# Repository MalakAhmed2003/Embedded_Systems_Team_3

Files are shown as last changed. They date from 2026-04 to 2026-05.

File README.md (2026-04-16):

# Embedded Systems Course Project

The following repository contains different files of code for running a Maze Solver Robot that explores any given maze then generates the optimized path to run 
between the start and end points, then runs on this optimized path.
The Robot also has a bluetooth module that connects to the laptop and can be controlled through a custom website (which you can also filnd its python code here).
## Exploration and Optimized Path:
To get the Robot to explore and optimize the path taken to solve the maze:
1- Upload the Maze_Solver.ino code to the Robot Arduino 
2- Power up the system with ~ 9.4-9.6 V

### Hardware Architecture


### Code Architecture
maze_robot_architecture

## Running the Website:
To run the Website correctly and connect it to the Arduino through the HC-10 Bluetooth Module, follow the following steps:

1- Pair with HMSOFT.

2- Make sure it appears in the Bluetooth tab in the device manager.

3- In the Bluetooth tab in the Device Manager--> HMSOFT--> Details tab --> Bluetooth Device Address in the drop list --> (34:03:de:34:c7:9e)

4- Run hc10_bridge.py after changing the HC-10 known addresses to the address found in the device manager.

5- Run the Website.py

6- Change the serial print and read in Arduino code to be serial#, where # is based on the pins you are connecting your Hc-10 module to.

The Website should look like:


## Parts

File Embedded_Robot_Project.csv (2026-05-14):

Reference | Qty | Value | Datasheet | MP | Description
C1,C2 | 2 | 220u | https://www.lcsc.com/datasheet/C2163363.pdf |  | Polarized capacitor, small US symbol
C3,C8 | 2 | 15p | https://eu.mouser.com/datasheet/3/76/1/GRM022R60G474ME15-01A.pdf | GRM022R60G474ME15L | SMD capacitor X5R(EIA) with capacitance 0.47uF Tol.20%. Rated voltage 4Vdc 85C
C4 | 1 | 1u | https://eu.mouser.com/datasheet/3/76/1/GRM022R60G474ME15-01A.pdf | GRM022R60G474ME15L | SMD capacitor X5R(EIA) with capacitance 0.47uF Tol.20%. Rated voltage 4Vdc 85C
C5,C6 | 2 | 12p | https://eu.mouser.com/datasheet/3/76/1/GRM022R60G474ME15-01A.pdf | GRM022R60G474ME15L | SMD capacitor X5R(EIA) with capacitance 0.47uF Tol.20%. Rated voltage 4Vdc 85C
C7,C26,C27,C28,C29,C32,C34 | 7 | 100n | https://eu.mouser.com/datasheet/3/76/1/GRM022R60G474ME15-01A.pdf | GRM022R60G474ME15L | SMD capacitor X5R(EIA) with capacitance 0.47uF Tol.20%. Rated voltage 4Vdc 85C
C9,C10 | 2 | 18p | https://eu.mouser.com/datasheet/3/76/1/GRM022R60G474ME15-01A.pdf | GRM022R60G474ME15L | SMD capacitor X5R(EIA) with capacitance 0.47uF Tol.20%. Rated voltage 4Vdc 85C
C11,C12,C13 | 3 | 1p | https://eu.mouser.com/datasheet/3/76/1/GRM022R60G474ME15-01A.pdf | GRM022R60G474ME15L | SMD capacitor X5R(EIA) with capacitance 0.47uF Tol.20%. Rated voltage 4Vdc 85C
C14,C15 | 2 | 47u | https://eu.mouser.com/datasheet/3/76/1/GRM022R60G474ME15-01A.pdf |  | Polarized capacitor
C16,C17,C18,C19,C20,C21,C22,C23,C24,C25 | 10 | 0u1 | https://eu.mouser.com/datasheet/3/76/1/GRM022R60G474ME15-01A.pdf | GRM022R60G474ME15L | SMD capacitor X5R(EIA) with capacitance 0.47uF Tol.20%. Rated voltage 4Vdc 85C
C30,C31 | 2 | 22p | https://eu.mouser.com/datasheet/3/76/1/GRM022R60G474ME15-01A.pdf | GRM022R60G474ME15L | SMD capacitor X5R(EIA) with capacitance 0.47uF Tol.20%. Rated voltage 4Vdc 85C
C33 | 1 | 10u | https://eu.mouser.com/datasheet/3/76/1/GRM022R60G474ME15-01A.pdf | GRM022R60G474ME15L | SMD capacitor X5R(EIA) with capacitance 0.47uF Tol.20%. Rated voltage 4Vdc 85C
D1,D2,D3,D4,D5,D6,D7,D8,D9,D10,D19,D21,D22 | 13 | LED | https://www.digikey.com/en/products/detail/kingbright/APT2012SURCK/1747532 | APT2012SURCK | Light emitting diode
D11,D12,D13,D14,D15,D16,D17,D18 | 8 | 1N4007 | http://www.vishay.com/docs/88503/1n4001.pdf |  | 1000V 1A General Purpose Rectifier Diode, DO-41
D20 | 1 | 1N4001 | http://www.vishay.com/docs/88503/1n4001.pdf |  | 50V 1A General Purpose Rectifier Diode, DO-41
F1 | 1 | MF-MSMF050-2 | https://www.lcsc.com/datasheet/C17313.pdf | MF-MSMF050-2 | Fuse, Resettable, 100A, Sz 4532, 0.186x0.134x0.033, SMT, 15VDC, DCR 0.15 Ohms | Bourns MF-MSMF050-2
FL1 | 1 | BLM21SP111SH1D | https://pim.murata.com/asset/pim4/ferriteBeadInductortypefilter/QNFA9102_PDF_FERRITEBEADINDUCTORTYPEFILTER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 | BLM21SP111SH1D | Ferrite Beads Multi-Layer Power 110Ohm 25% 100MHz 5A 0.013Ohm DCR 0805 Automotive T/R
J1,J2,J4 | 3 | Screw_Terminal_01x02 | https://www.lcsc.com/datasheet/C590402.pdf |  | Generic screw terminal, single row, 01x02, script generated (kicad-library-utils/schlib/autogen/connector/)
J3 | 1 | Screw_Terminal_01x03 | https://www.lcsc.com/datasheet/C5172715.pdf |  | Generic screw terminal, single row, 01x03, script generated (kicad-library-utils/schlib/autogen/connector/)
J6 | 1 | USB_B | https://www.lcsc.com/datasheet/C720549.pdf | 292304-1 | Type B Standard USB Connector 4 Position Right Angle Mount 1 Port | TE Connectivity 292304-1
L1,L2 | 2 | 2n | https://www.lcsc.com/datasheet/C76769.pdf | MLG1005S2N0BT000 | 2 nH Unshielded Multilayer Inductor 900 mA 150mOhm Max 0402 (1005 Metric)
L3 | 1 | 1n | https://www.lcsc.com/datasheet/C76769.pdf | MLG1005S2N0BT000 | 2 nH Unshielded Multilayer Inductor 900 mA 150mOhm Max 0402 (1005 Metric)
L4 | 1 | 3n | https://www.lcsc.com/datasheet/C76769.pdf | MLG1005S2N0BT000 | 2 nH Unshielded Multilayer Inductor 900 mA 150mOhm Max 0402 (1005 Metric)
R1,R3,R5,R6,R8,R9,R12,R13,R14,R17,R18,R19,R22,R23,R24,R26,R28,R32,R33,R34,R35,R36,R37 | 23 | 1K | https://www.mouser.com/catalog/specsheets/YAGEO_PYu_RC_Group_51_RoHS_L_12.pdf | RC0100FR-071KL | 1 kOhms ±1% 0.03W, 1/32W Chip Resistor 01005 (0402 Metric) Moisture Resistant Thick Film
R2,R4,R7,R10,R11,R15,R16,R20,R21,R25 | 10 | 10K | https://www.mouser.com/catalog/specsheets/YAGEO_PYu_RC_Group_51_RoHS_L_12.pdf | RC0100FR-071KL | 1 kOhms ±1% 0.03W, 1/32W Chip Resistor 01005 (0402 Metric) Moisture Resistant Thick Film
R27 | 1 | 56K | https://www.mouser.com/catalog/specsheets/YAGEO_PYu_RC_Group_51_RoHS_L_12.pdf | RC0100FR-071KL | 1 kOhms ±1% 0.03W, 1/32W Chip Resistor 01005 (0402 Metric) Moisture Resistant Thick Film
R29 | 1 | 2K | https://www.mouser.com/catalog/specsheets/YAGEO_PYu_RC_Group_51_RoHS_L_12.pdf | RC0100FR-071KL | 1 kOhms ±1% 0.03W, 1/32W Chip Resistor 01005 (0402 Metric) Moisture Resistant Thick Film
R30,R31 | 2 | 1M | https://www.mouser.com/catalog/specsheets/YAGEO_PYu_RC_Group_51_RoHS_L_12.pdf | RC0100FR-071KL | 1 kOhms ±1% 0.03W, 1/32W Chip Resistor 01005 (0402 Metric) Moisture Resistant Thick Film
RV1,RV2 | 2 | CG0603MLC-05E | https://eu.mouser.com/datasheet/3/40/1/cg0603mlc_05e_cg0603mlc_12e.pdf | CG0603MLC-05E | Varistor, ESD Clamp Protector, 5 VDC, 20 Vclamp, IEC 61000-4-2 Level 4, 0603 SMD | Bourns CG0603MLC-05E
S1 | 1 | TS20-42-25-WT-160-SMT-TR | https://www.lcsc.com/datasheet/C6886437.pdf | TS20-42-25-WT-160-SMT-TR | 4.2 x 3.2 mm, 2.5 mm Actuator Height, 160 gf, White, Surface Mount, TR, SPST, Tactile Switch
U1,U3,U5,U7,U9 | 5 | TCRT5000 | https://www.lcsc.com/datasheet/C24085.pdf | TCRT5000 | 950 nm 60 mA Through Hole Reflective Optical Sensor with Transistor Output
U2,U4,U6,U8,U10 | 5 | LM393AD | https://www.ti.com/lit/ds/symlink/lm193.pdf?HQS=dis-mous-null-mousermode-dsf-pf-null-wwe&ts=1778583813238 | LM393AD | Precision dual differential comparator, industrial grade
U11 | 1 | L298N | http://www.st.com/st-web-ui/static/active/en/resource/technical/document/datasheet/CD00000240.pdf |  | Dual full bridge motor driver, up to 46V, 4A, Multiwatt15-V
U12 | 1 | KA78M05_TO252 | https://www.onsemi.com/pub/Collateral/MC78M00-D.PDF |  | Positive 500mA 35V Linear Regulator, Fixed Output 5V, TO-252 (D-PAK)
U13 | 1 | CC2540F256RHAT | https://www.ti.com/lit/ds/symlink/cc2540.pdf?ts=1778516829410 | CC2540F256RHAT | Bluetooth® Low Energy wireless MCU with USB
U14 | 1 |  | https://www.ti.com/lit/an/swra117d/swra117d.pdf |  | 2.4 GHZ Antenna
U15 | 1 | ATmega2560-16A | http://ww1.microchip.com/downloads/en/DeviceDoc/Atmel-2549-8-bit-AVR-Microcontroller-ATmega640-1280-1281-2560-2561_datasheet.pdf |  | 16MHz, 256kB Flash, 8kB SRAM, 4kB EEPROM, JTAG, TQFP-100
U16 | 1 | ATmega16U2-M | http://ww1.microchip.com/downloads/en/DeviceDoc/doc7799.pdf |  | 16MHz, 16kB Flash, 512B SRAM, 512B EEPROM, QFN-32
U17 | 1 | NCP1117-3.3_TO252 | http://www.onsemi.com/pub_link/Collateral/NCP1117-D.PDF |  | 1A Low drop-out regulator, Fixed Output 3.3V, TO-252 (DPAK)
VR3,VR4,VR5,VR6,VR7 | 5 | Variable_Resistor_3362P | https://www.lcsc.com/datasheet/C48997906.pdf | 3362P-1-103RLF | TRIMMER - 1/4in SQ ST CERMET | Bourns 3362P-1-103RLF
Y1 | 1 | 32K | https://www.lcsc.com/datasheet/C6524090.pdf | SXT2248BB48-32.000M | Crystal 32MHz ±30ppm (Tol) ±30ppm (Stability) 8pF FUND 60Ohm Medical 4-Pin Ultra Mini-CSMD T/R
Y2 | 1 | 32M | https://www.lcsc.com/datasheet/C6524090.pdf | SXT2248BB48-32.000M | Crystal 32MHz ±30ppm (Tol) ±30ppm (Stability) 8pF FUND 60Ohm Medical 4-Pin Ultra Mini-CSMD T/R
Y3 | 1 | 16M | https://www.lcsc.com/datasheet/C6524090.pdf | SXT2248BB48-32.000M | Crystal 32MHz ±30ppm (Tol) ±30ppm (Stability) 8pF FUND 60Ohm Medical 4-Pin Ultra Mini-CSMD T/R
Y4 | 1 | 16M | https://www.lcsc.com/datasheet/C341521.pdf | CSTCE16M0V53R0 | RESONATOR, CERAMIC, 16MHZ, SMD; Frequency:16MHz; Oscillator Mounting:SMD; No. of Pins:3 Pin; Resonant Impedance:40ohm; Frequency Tolerance:± 0.5%; Product Range:-; Frequency Stability:-; Operating Temperature Min:-20°C; Operating Temperature Max:80°C; SVHC:No SVHC (07-Jul-2017); No. of Pins:3Pins

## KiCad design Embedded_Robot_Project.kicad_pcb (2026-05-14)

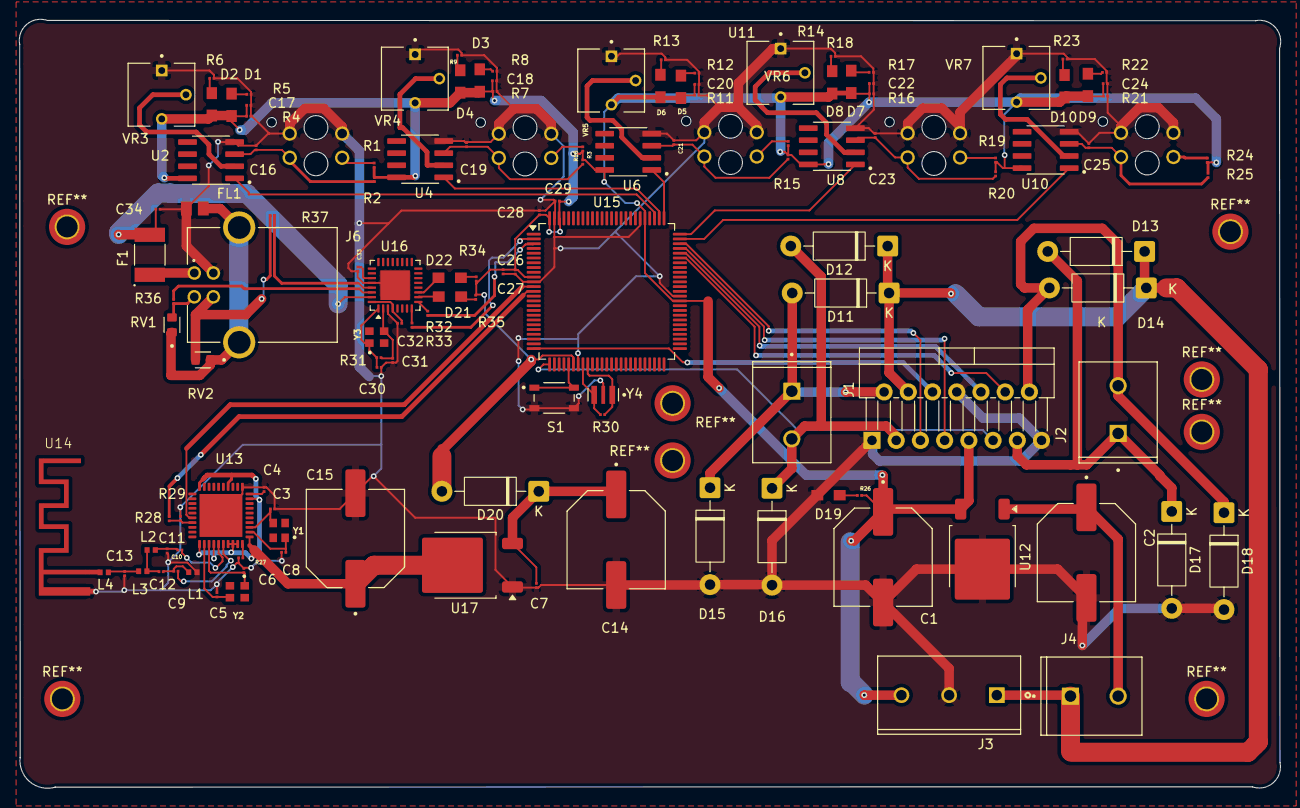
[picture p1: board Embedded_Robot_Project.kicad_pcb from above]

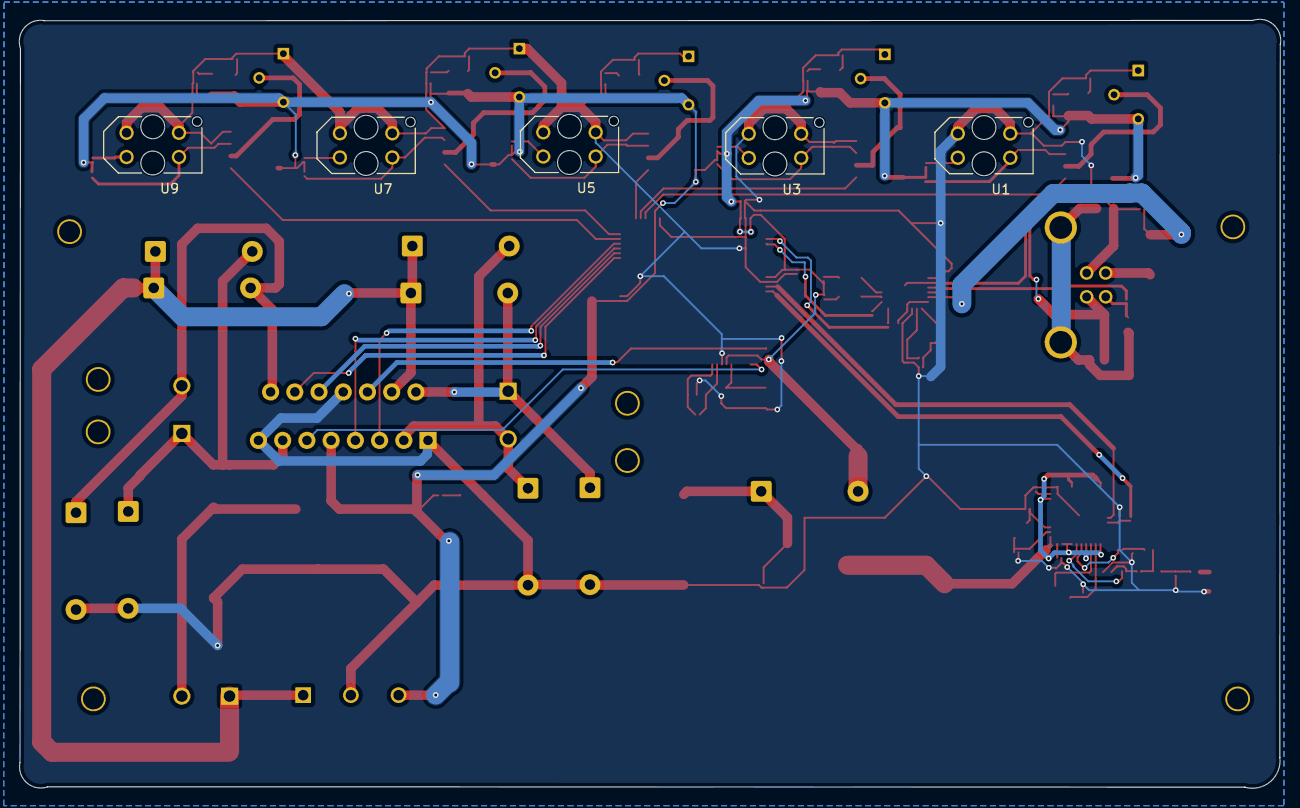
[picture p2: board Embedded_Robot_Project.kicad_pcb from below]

Board: 2 copper layers, 132.3 x 80.6 mm, 133 parts (5 on the bottom side), 85 nets.

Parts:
C1, C2: C_Polarized_Small_US; CAP_Polarized
C3, C4, C5, C6, C7, C8, C9, C10, C11, C12, C13, C16, C17, C18, C19, C20, C21, C22, C23, C24, C25, C26, C27, C28, C29, C30, C31, C32, C33, C34: GRM022R60G474ME15L; CAP_0402
C14, C15: C_Polarized; CAP_Polarized
D1, D2, D3, D4, D5, D6, D7, D8, D9, D10, D19, D21, D22: LED; LED_APT2012SURCK
D11, D12, D13, D14, D15, D16, D17, D18: 1N4007; D_DO-41_SOD81_P10.16mm_Horizontal
D20: 1N4001; D_DO-41_SOD81_P10.16mm_Horizontal
F1: MF-MSMF050-2; FUSM4632X85
FL1: BLM21SP111SH1D; BLM21
J1, J2, J4: Screw_Terminal_01x02; Screw_Connector_2
J3: Screw_Terminal_01x03; Screw_Connector_3
J6: TE_292304-1; USB_B
L1, L2, L3, L4: MLG1005S2N0BT000; INDC_01005
R1, R2, R3, R4, R5, R6, R7, R8, R9, R10, R11, R12, R13, R14, R15, R16, R17, R18, R19, R20, R21, R22, R23, R24, R25, R26, R27, R28, R29, R30, R31, R32, R33, R34, R35, R36, R37: RC0100FR-071KL; R_01005
RV1, RV2: CG0603MLC-05E; VARistor
S1: TS20-42-25-WT-160-SMT-TR; SW_Reset
U1, U3, U5, U7, U9: *; OPTO_TCRT5000
U2, U4, U6, U8, U10: LM393AD; LM393
U11: L298N; TO-220-15_P2.54x5.08mm_StaggerOdd_Lead4.58mm_Vertical
U12: KA78M05_TO252; TO-252-2
U13: CC2540F256RHAT; CC2540
U14: Antenna_BLE
U15: ATmega2560-16A; TQFP-100_14x14mm_P0.5mm
U16: ATmega16U2-M; QFN-32-1EP_5x5mm_P0.5mm_EP3.1x3.1mm
U17: NCP1117-3.3_TO252; TO-252-2
VR3, VR4, VR5, VR6, VR7: Variable_Resistor_3362P; Potontiometer
Y1, Y2, Y3: XTAL_Crystal_Oscillator; XTAL_Footprint
Y4: CSTCE16M0V53-R0; OSC_16M0V53_Arduino

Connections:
/Arduino_Mega/EN_A_Arduino: U11.6 (EnA), U15.25 (PB6)
/Arduino_Mega/EN_B_Arduino: U11.11 (EnB), U15.26 (PB7)
/Arduino_Mega/IN_1_Arduino: U11.5 (IN1), U15.73 (PA5)
/Arduino_Mega/IN_2_Arduino: U11.7 (IN2), U15.72 (PA6)
/Arduino_Mega/IN_3_Arduino: U11.10 (IN3), U15.71 (PA7)
/Arduino_Mega/IN_4_Arduino: U11.12 (IN4), U15.70 (PG2)
/Arduino_Mega/PE0: R33.1, U15.2 (PE0)
/Arduino_Mega/PE1: R32.1, U15.3 (PE1)
/Arduino_Mega/RX_2_Arduino: U13.16 (P0_3), U15.12 (PH0)
/Arduino_Mega/S_1_Arduino: U2.1 (1OUT), U15.78 (PA0)
/Arduino_Mega/S_2_Arduino: U4.1 (1OUT), U15.77 (PA1)
/Arduino_Mega/S_3_Arduino: U6.1 (1OUT), U15.76 (PA2)
/Arduino_Mega/S_4_Arduino: U8.1 (1OUT), U15.75 (PA3)
/Arduino_Mega/S_5_Arduino: U10.1 (1OUT), U15.74 (PA4)
/Arduino_Mega/TX_2_Arduino: R28.1, U15.13 (PH1)
/Arduino_Mega/USB_VCC: C34.2, F1.2, U16.31 (UVCC)
/BLE_HC_05/3.3V: C15.1, U13.4 (DVDD_USB), U13.10 (DVDD), U13.21 (AVDD), U13.24 (AVDD__1), U13.27 (AVDD__2), U13.28 (AVDD__3), U13.29 (AVDD__4), U13.31 (AVDD__5), U13.39 (DVDD__1), U17.2 (VO)
/BLE_HC_05/Pin_25: C10.1, U13.25 (RF_P)
/BLE_HC_05/Pin_26: C9.1, U13.26 (RF_N)
/BLE_HC_05/RX_BLE: R28.2, R29.1, U13.17 (P0_2)
/IR_Sensors/AO1: C16.2, R2.1, U1.COLL, U2.3 (1IN+)
/IR_Sensors/AO2: C19.2, R10.1, U3.COLL, U4.3 (1IN+)
/IR_Sensors/AO3: C21.2, R15.1, U5.COLL, U6.3 (1IN+)
/IR_Sensors/AO4: C23.2, R20.1, U7.COLL, U8.3 (1IN+)
/IR_Sensors/AO5: C25.2, R25.1, U9.COLL, U10.3 (1IN+)
GND: C1.2, C2.2, C3.1, C4.1, C5.1, C6.1, C7.1, C8.1, C11.1, C13.1, C14.2, C15.2, C16.1, C17.1, C18.1, C19.1, C20.1, C21.1, C22.1, C23.1, C24.1, C25.1, C26.2, C27.2, C28.2, C29.1, C30.2, C31.2, C32.1, C33.2, C34.1, D15.2 (A), D16.2 (A), D17.2 (A), D18.2 (A), D19.1 (K), FL1.2, J3.2, J6.4 (GND), L1.2, R4.1, R5.1, R6.1, R7.1, R8.1, R9.1, R11.1, R12.1, R13.1, R16.1, R17.1, R18.1, R21.1, R22.1, R23.1, R27.1, R29.2, S1.3, S1.4, U1.CATH, U1.E, U2.4 (GND), U3.CATH, U3.E, U4.4 (GND), U5.CATH, U5.E, U6.4 (GND), U7.CATH, U7.E, U8.4 (GND), U9.CATH, U9.E, U10.4 (GND), U11.1 (SENSE_A), U11.8 (GND), U11.15 (SENSE_B), U12.2 (GND), U13.1 (DGND_USB), U13.EXP (GND), U14.2, U15.11 (GND), U15.32 (GND), U15.62 (GND), U15.81 (GND), U15.99 (GND), U16.3 (GND), U16.28 (UGND), U16.33 (GND), U17.1 (GND), VR3.1, VR4.1, VR5.1, VR6.1, VR7.1, Y4.2
unnamed: C10.2, C11.2, L2.1
unnamed: C9.2, C12.1, L1.1
unnamed: C12.2, L2.2, L3.1
unnamed: C13.2, L3.2, L4.1
unnamed: D1.1 (K), R5.2
unnamed: D2.1 (K), R6.2
unnamed: D3.1 (K), R8.2
unnamed: D4.1 (K), R9.2
unnamed: D5.1 (K), R12.2
unnamed: D6.1 (K), R13.2
unnamed: D7.1 (K), R17.2
unnamed: D8.1 (K), R18.2
unnamed: D9.1 (K), R22.2
unnamed: D10.1 (K), R23.2
unnamed: D11.2 (A), D15.1 (K), J1.1, U11.2 (OUT1)
unnamed: D12.2 (A), D16.1 (K), J1.2, U11.3 (OUT2)
unnamed: D13.2 (A), D17.1 (K), J2.1, U11.13 (OUT3)
unnamed: D14.2 (A), D18.1 (K), J2.2, U11.14 (OUT4)
unnamed: D19.2 (A), R26.1
unnamed: C7.2, C14.1, D20.1 (K), U17.3 (VI)
unnamed: D21.2 (A), R35.2
unnamed: D21.1 (K), U16.10 (PD4)
unnamed: D22.2 (A), R34.2
unnamed: D22.1 (K), U16.11 (PD5)
unnamed: C2.1, J4.2, U12.1 (VI)
unnamed: J6.3 (D+), R37.2, RV2.2
unnamed: J6.2 (D-), R36.2, RV1.2
unnamed: FL1.1, J6.S1 (SHIELD), J6.S2 (SHIELD__1), RV1.1, RV2.1
unnamed: F1.1, J6.1 (VBUS)
unnamed: L4.2, U14.1
unnamed: R1.1, U1.A
unnamed: R3.1, U3.A
unnamed: R14.1, U5.A
unnamed: R19.1, U7.A
unnamed: R24.1, U9.A
unnamed: U2.2 (1IN-), VR3.2
unnamed: U4.2 (1IN-), VR4.2
unnamed: U6.2 (1IN-), VR5.2
unnamed: U8.2 (1IN-), VR6.2
unnamed: U10.2 (1IN-), VR7.2
unnamed: C4.2, U13.40 (DCOUPL)
unnamed: C3.2, U13.33 (P2_3), Y1.3
unnamed: C8.2, U13.32 (P2_4), Y1.1
unnamed: R27.2, U13.30 (RBIAS)
unnamed: C5.2, U13.22 (XOSC_Q1), Y2.3
unnamed: C6.2, U13.23 (XOSC_Q2), Y2.1
unnamed: R30.2, U15.34 (XTAL1), Y4.1
unnamed: R30.1, U15.33 (XTAL2), Y4.3
unnamed: S1.1, S1.2, U15.30 (~RESET)
unnamed: C32.2, U16.4 (VCC), U16.32 (AVCC)
unnamed: R37.1, U16.29 (D+)
unnamed: R36.1, U16.30 (D-)
unnamed: C31.1, R31.1, U16.2 (PC0/XTAL2), Y3.3
unnamed: R33.2, U16.8 (PD2)
unnamed: R32.2, U16.9 (PD3)
unnamed: C33.1, U16.27 (UCAP)
unnamed: C30.1, R31.2, U16.1 (XTAL1), Y3.1
Power_In: D11.1 (K), D12.1 (K), D13.1 (K), D14.1 (K), J3.1, J4.1, U11.4 (Vs)
VCC: C1.1, C17.2, C18.2, C20.2, C22.2, C24.2, C26.1, C27.1, C28.1, C29.2, D1.2 (A), D2.2 (A), D3.2 (A), D4.2 (A), D5.2 (A), D6.2 (A), D7.2 (A), D8.2 (A), D9.2 (A), D10.2 (A), D20.2 (A), J3.3, R1.2, R2.2, R3.2, R4.2, R7.2, R10.2, R11.2, R14.2, R15.2, R16.2, R19.2, R20.2, R21.2, R24.2, R25.2, R26.2, R34.1, R35.1, U2.8 (VCC), U4.8 (VCC), U6.8 (VCC), U8.8 (VCC), U10.8 (VCC), U11.9 (Vss), U12.3 (VO), U15.10 (VCC), U15.31 (VCC), U15.61 (VCC), U15.80 (VCC), U15.98 (AREF), U15.100 (AVCC), VR3.3, VR4.3, VR5.3, VR6.3, VR7.3

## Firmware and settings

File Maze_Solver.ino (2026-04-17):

// IR sensors pin assignment
#define S0 A0
#define S1 A1
#define S2 A2
#define S3 A3
#define S4 A4

// Motor driver pin assignment
#define IN1 8
#define IN2 9
#define IN3 10
#define IN4 11
#define ENA 5
#define ENB 6

// Speeds assignemnt
int baseSpeed = 60;
int turnSpeed = 90;

// PD controller variables for smooth movement
float Kp = 50;
float Kd = 60;

// Path tracking vector creation
char path[200] = "";
int pathLength = 0;
bool mazeSolved = false;
bool runOptimizedMode = false;
int pathIndex = 0;            

// Creating an inIntersection variable to track whether the robot got out of the
// intersection or not to avoid any messy direction recordings, i.e to avoid repeating same direction while still turning on the intersection
bool inIntersection = false;
bool explorationStarted = false;

// Different sensor states
int LeftFar, LeftNear, Center, RightNear, RightFar;

// Global orientation methodology
enum Direction { NORTH = 0, EAST = 1, SOUTH = 2, WEST = 3 };

Direction startDirection = NORTH; 
Direction currentDirection = startDirection;

char getGlobalHeading() {
  switch (currentDirection) {
    case NORTH: return 'N';
    case EAST:  return 'E';
    case SOUTH: return 'S'; 
    case WEST:  return 'W';
    default:    return '?';
  }
}

void setup() {
  Serial3.begin(9600);

  pinMode(S0, INPUT);
  pinMode(S1, INPUT);
  pinMode(S2, INPUT);
  pinMode(S3, INPUT);
  pinMode(S4, INPUT);

  pinMode(IN1, OUTPUT);
  pinMode(IN2, OUTPUT);
  pinMode(IN3, OUTPUT);
  pinMode(IN4, OUTPUT);
  pinMode(ENA, OUTPUT);
  pinMode(ENB, OUTPUT);

  Serial3.print("Robot Started (Facing ");
  Serial3.print(getGlobalHeading());
  Serial3.println(")");
  Serial3.println("Type 'start' to begin exploration");
}

int stableRead(int pin) {
  int count0 = 0, count1 = 0;

  for (int i = 0; i < 5; i++) {
    if (digitalRead(pin) == 0) count0++;
    else count1++;
    delay(2);
  }

  return (count0 > count1) ? 0 : 1;
}

void readSensors() {
  int sumS0 = 0, sumS1 = 0, sumS2 = 0, sumS3 = 0, sumS4 = 0;
  int samples = 2;

  for (int i = 0; i < samples; i++) {
    sumS0 += digitalRead(S0);
    sumS1 += digitalRead(S1);
    sumS2 += digitalRead(S2);
    sumS3 += digitalRead(S3);
    sumS4 += digitalRead(S4);
    delay(1); 
  }

  LeftFar   = (sumS0 > samples / 2) ? 1 : 0;
  LeftNear  = (sumS1 > samples / 2) ? 1 : 0;
  Center    = (sumS2 > samples / 2) ? 1 : 0;
  RightNear = (sumS3 > samples / 2) ? 1 : 0;
  RightFar  = (sumS4 > samples / 2) ? 1 : 0;
}

void forward() {
  digitalWrite(IN1, LOW);
  digitalWrite(IN2, HIGH);
  digitalWrite(IN3, HIGH);
  digitalWrite(IN4, LOW);
  analogWrite(ENA, baseSpeed);
  analogWrite(ENB, baseSpeed);
}

void stopMotors() {
  analogWrite(ENA, 0);
  analogWrite(ENB, 0);
}

void pdControlFollow(int LN, int C, int RN) {
  static int lastError = 0;
  int error = 0;

  if      (LN == 0 && C == 1 && RN == 1) error = -2;      
  else if (LN == 0 && C == 0 && RN == 1) error = -1; 
  else if (LN == 1 && C == 0 && RN == 1) error = 0;  
  else if (LN == 1 && C == 0 && RN == 0) error = 1;  
  else if (LN == 1 && C == 1 && RN == 0) error = 2;  
  else error = lastError; 

  int derivative = error - lastError;
  int correction = (Kp * error) + (Kd * derivative);
  lastError = error;

  int leftSpeed = baseSpeed + correction; 
  int rightSpeed = baseSpeed - correction;

  leftSpeed = constrain(leftSpeed, 0, 255);
  rightSpeed = constrain(rightSpeed, 0, 255);

  digitalWrite(IN1, LOW);
  digitalWrite(IN2, HIGH);
  digitalWrite(IN3, HIGH);
  digitalWrite(IN4, LOW);
  analogWrite(ENA, leftSpeed);
  analogWrite(ENB, rightSpeed);
}

void turnLeft90() {
  digitalWrite(IN1, HIGH);
  digitalWrite(IN2, LOW);
  digitalWrite(IN3, HIGH);
  digitalWrite(IN4, LOW);

  analogWrite(ENA, turnSpeed);
  analogWrite(ENB, turnSpeed);

  delay(250);
  while (stableRead(S2) == 1);

  stopMotors();
}

void turnRight90() {
  digitalWrite(IN1, LOW);
  digitalWrite(IN2, HIGH);
  digitalWrite(IN3, LOW);
  digitalWrite(IN4, HIGH);

  analogWrite(ENA, turnSpeed);
  analogWrite(ENB, turnSpeed);

  delay(250);
  while (stableRead(S2) == 1);

  stopMotors();
}

void turn180() {
  digitalWrite(IN1, LOW);
  digitalWrite(IN2, HIGH);
  digitalWrite(IN3, LOW);
  digitalWrite(IN4, HIGH);

  analogWrite(ENA, turnSpeed);
  analogWrite(ENB, turnSpeed);

  delay(500);
  while (stableRead(S2) == 1);

  stopMotors();
}

void updateLeft()  { currentDirection = (Direction)((currentDirection + 3) % 4); }
void updateRight() { currentDirection = (Direction)((currentDirection + 1) % 4); }
void updateBack()  { currentDirection = (Direction)((currentDirection + 2) % 4); }

void recordMove(char localMove) {
  if (mazeSolved) return;
  char globalMove = getGlobalHeading();
  path[pathLength++] = globalMove;
  path[pathLength] = '\0';
  Serial3.print("Local Action: ");
  Serial3.print(localMove);
  Serial3.print(" | Global Heading Recorded: ");
  Serial3.println(globalMove);
}

void optimizePath() {
  bool changed = true;
  while (changed) {
    changed = false;
    for (int i = 0; i < pathLength - 1; i++) {
      if ((path[i] == 'N' && path[i+1] == 'S') ||
          (path[i] == 'S' && path[i+1] == 'N') ||
          (path[i] == 'E' && path[i+1] == 'W') ||
          (path[i] == 'W' && path[i+1] == 'E')) {
        
        for (int j = i; j < pathLength - 2; j++) {
          path[j] = path[j+2];
        }
        pathLength -= 2;
        path[pathLength] = '\0'; 
        changed = true;
        break; 
      }
    }
  }
  Serial3.println("=== OPTIMIZED GLOBAL PATH ===");
  Serial3.println(path);
}

void runOptimizedPath() {
  readSensors(); 

  // end goal detection
  if (pathIndex >= pathLength && 
      LeftFar == 0 && LeftNear == 0 && Center == 0 && 
      RightNear == 0 && RightFar == 0) {
    
    forward();
    delay(50);

    unsigned long startTime = millis();
    while (millis() - startTime < 200) {
      readSensors();
      if (LeftFar != 0 || LeftNear != 0 || Center != 0 || 
          RightNear != 0 || RightFar != 0) {
        return;
      }
    }

    stopMotors();
    Serial3.println("=== OPTIMIZED MAZE SOLVED! ===");
    runOptimizedMode = false;
    pathIndex = 0;
    inIntersection = false;
    return;
  }

  // Intersection detection
  bool isJunction = (LeftFar == 0 || RightFar == 0);

  if (isJunction && !inIntersection) {
    
    // Check available paths
    bool canTurnLeft = (LeftFar == 0);
    bool canTurnRight = (RightFar == 0);

    // Center into intersection 
    unsigned long centerStartTime = millis();
    forward();
    
    while (millis() - centerStartTime < 150) {
      readSensors();
      if (LeftFar == 0) canTurnLeft = true;
      if (RightFar == 0) canTurnRight = true;
    }
    stopMotors();

    // Check straight path (same as exploration)
    int straightPathExists = stableRead(S2);
    bool canGoStraight = (straightPathExists == 0);

    // Get target global direction from optimized path
    if (pathIndex < pathLength) {
      char targetGlobal = path[pathIndex];
      Direction targetDir = currentDirection;

      if (targetGlobal == 'N') targetDir = NORTH;
      else if (targetGlobal == 'E') targetDir = EAST;
      else if (targetGlobal == 'S') targetDir = SOUTH;
      else if (targetGlobal == 'W') targetDir = WEST;

      // Calculate which way to turn
      int turnDiff = (targetDir - currentDirection + 4) % 4;

      // Execute based on turnDiff, but verify path is available
      if (turnDiff == 3 && canTurnLeft) {  // Left turn
        turnLeft90();
        updateLeft();
        Serial3.print("Turned LEFT at junction, now facing ");
        Serial3.println(getGlobalHeading());
        pathIndex++;
      }
      else if (turnDiff == 1 && canTurnRight) {  // Right turn
        turnRight90();
        updateRight();
        Serial3.print("Turned RIGHT at junction, now facing ");
        Serial3.println(getGlobalHeading());
        pathIndex++;
      }
      else if (turnDiff == 0 && canGoStraight) {  // Straight
        Serial3.println("Going STRAIGHT at junction");
        pathIndex++;
      }
      else if (turnDiff == 2) {  // U-turn
        turn180();
        updateBack();
        Serial3.println("Turned BACK at junction");
        pathIndex++;
      }
      else {
        // If path mismatch what obot sees, follow (Left > Straight > Right)
        Serial3.print("WARNING: Path wants ");
        Serial3.print(targetGlobal);
        Serial3.print(" but not available. Using exploration logic. Path index: ");
        Serial3.println(pathIndex);
        
        if (canTurnLeft) {
          turnLeft90();
          updateLeft();
          Serial3.println("Exploration fallback: Turning LEFT");
          pathIndex++;
        }
        else if (canGoStraight) {
          Serial3.println("Exploration fallback: Going STRAIGHT");
          pathIndex++;
        }
        else if (canTurnRight) {
          turnRight90();
          updateRight();
          Serial3.println("Exploration fallback: Turning RIGHT");
          pathIndex++;
        }
      }
    }
    
    inIntersection = true;
    
    Serial3.print("Path progress: ");
    Serial3.print(pathIndex);
    Serial3.print("/");
    Serial3.println(pathLength);
  }
  
  // Line following
  else if (Center == 0 || LeftNear == 0 || RightNear == 0) {
    pdControlFollow(LeftNear, Center, RightNear);
  }

  // Exit intersection condition
  if (Center == 0 && RightNear == 1 && LeftNear == 1 && 
      RightFar == 1 && LeftFar == 1) {
    inIntersection = false;
    Serial3.println("Exited intersection");
  }

  // Dead end detection
  if (LeftFar == 1 && LeftNear == 1 && Center == 1 && 
      RightNear == 1 && RightFar == 1) {
    
    unsigned long startTime = millis();
    bool isDeadEnd = true;

    while (millis() - startTime < 200) {
      readSensors();
      if (LeftFar == 0 || LeftNear == 0 || Center == 0 || 
          RightNear == 0 || RightFar == 0) {
        isDeadEnd = false;
        break;
      }
    }
    
    if (isDeadEnd) {
      turn180();
      updateBack();
      Serial3.println("Dead end detected in optimized run");
      return;
    }
  }
}

void loop() {
  if (Serial3.available() > 0) {
    String command = Serial3.readStringUntil('\n');
    command.trim();
    
    if (command.equalsIgnoreCase("start")) {
      if (!mazeSolved && !explorationStarted) {
        explorationStarted = true;
      }
    }
    else if (command.equalsIgnoreCase("optimized")) {
      if (mazeSolved) {
        runOptimizedMode = true;
        pathIndex = 0;
        currentDirection = startDirection;
        inIntersection = false;
        delay(1000);
      }
    }
    else if (command.equalsIgnoreCase("stop")) {
      stopMotors();
      runOptimizedMode = false;
      explorationStarted = false;
    }
    else if (command.equalsIgnoreCase("optimize")) {
      if (mazeSolved) {
        optimizePath();
      }
    }
  }

  if (mazeSolved && !runOptimizedMode) {
    return; 
  }

  if (runOptimizedMode) {
    runOptimizedPath();
    return;
  }

  if (!explorationStarted || mazeSolved) {
    return;
  }

  readSensors(); 

  if (LeftFar == 0 && LeftNear == 0 && Center == 0 && RightNear == 0 && RightFar == 0) {
    forward();
    delay(50);

    unsigned long startTime = millis();
    while (millis() - startTime < 200) {
      readSensors();
      if (LeftFar != 0 || LeftNear != 0 || Center != 0 || RightNear != 0 || RightFar != 0) {
        return; 
      }
    }

    stopMotors();
    mazeSolved = true;
    
    Serial3.println("=== MAZE SOLVED ===");
    Serial3.print("Raw Path: ");
    Serial3.println(path);
    optimizePath();
    Serial3.println("Type 'optimized' to run the fast path.");
    return; 
  }

  bool isJunction = (LeftFar == 0 || RightFar == 0);

  if (isJunction && !inIntersection) {
    
    bool canTurnLeft = (LeftFar == 0);
    bool canTurnRight = (RightFar == 0);

    unsigned long centerStartTime = millis();
    forward();
    
    while (millis() - centerStartTime < 150) {
      readSensors(); 
      if (LeftFar == 0) canTurnLeft = true;
      if (RightFar == 0) canTurnRight = true;
    }
    stopMotors();

    int straightPathExists = stableRead(S2);
    bool canGoStraight = (straightPathExists == 0);

    if (canTurnLeft) {
      turnLeft90();
      updateLeft();
      recordMove('L');
    }
    else if (canGoStraight) {
      recordMove('S');
    }
    else if (canTurnRight) {
      turnRight90();
      updateRight();
      recordMove('R');
    }
    
    inIntersection = true;
  }
  
  else if (Center == 0 || LeftNear == 0 || RightNear == 0) {
    pdControlFollow(LeftNear, Center, RightNear);
  }

  if (Center == 0 && RightNear == 1 && LeftNear == 1 && RightFar == 1 && LeftFar == 1) {
    inIntersection = false;
  }

  if (LeftFar == 1 && LeftNear == 1 && Center == 1 && RightNear == 1 && RightFar == 1) {
      
    unsigned long startTime = millis();
    bool isDeadEnd = true;

    while (millis() - startTime < 200) {
      readSensors();
      if (LeftFar == 0 || LeftNear == 0 || Center == 0 || RightNear == 0 || RightFar == 0) {
        isDeadEnd = false;
        break;
      }
    }
    
    if (isDeadEnd) {
      turn180();
      updateBack();
      recordMove('B');
      return;
    }
  }
}
